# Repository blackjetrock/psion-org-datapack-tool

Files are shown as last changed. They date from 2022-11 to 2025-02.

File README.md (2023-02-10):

# psion-org-datapack-tool
Datapack tool for Psion Organisers

IMAG3168

Status
======

** This is a work in progress and probably always will be **

The code builds and can read datapack data. It can also write datapack data. issues:
the OLED and buttons work and there are read and write and info options that work on the OLED.
A lot of funtionality is over USB serial.

0. There are errors on the fab1 PCB. these are listed in the errata. hand mods are needed to get the PCB to work.
1. Flash packs can't be written.
2. Read pak to file doesn't seem to give a valid opk file, not sure why
3. Detection of all the diffferent pack addressing schemes and sizes isn't there, really.
4. Could do with a detection routine.
5. The code is untidy...
6. The OLED and serial functions aren't very coherent.

Building
========

The firmware directory has the files required for building the code but
they are configured for my file system structure.
They will have to be altered to match the location of your SDK, where the FAT
FS library used will have to be located.

Set the PICO_SDK_DIR environment variable to point to the Pico SDK directory: 

export PICO_SDK_DIR="[where the Pico SDK is]"

create a 'build' directory in the 'firmware' directory and run:
cmake ..

then fix errors (should only be directories, probably the location of the FAT FS library in CMakeLists.txt)

Then :

make

Then program with either a picoprobe or as a UF2 file.

Picoprobe Programming
---------------------

There is a script in the firmware directory 

flash_code.sh

that will use openocd and a picprobe toprogram the code onto a Pico. 
Run this script from the build directory

../flash_code.sh

Openocd needs to be set up as detailed in the Pico documentation.
Some directories may need to be altered to match your structure.

There is also a script

../set_debug_openocd.sh

(also run from the build directory) that will set up gdb for a session. Run this from the 
build directory as well. It is set up to use the TUI (Text User Interface) 
with the -tui command line option, but that can be removed for a standard
gdb CLI experience.

Running
=======

There is an interface on the OLED display that uses the buttons. 

Left button:      Up
Middle Button:    Down
Right Button:     Action/Execute

There is a menu system to access all the functions.

There is also an interface that runs over the USB serial connectin from the 
Pico on the PCB to a host PC. I use minicom on Linux but any terminal emulator should work, 
e.g. the one in the Arduino SDK.

SD Card
=======

The SD card holds .opk images in a directory called 'PAK' that is located in the
root directory of the SD card. The SD card is checked at power on and a message 
appears on the OLED display indicating whether the check was OK or not.

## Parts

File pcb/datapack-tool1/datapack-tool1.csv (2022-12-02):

Id | Designator | Package | Quantity | Designation | Supplier and ref
1 | U4 | SOT-223-3_TabPin2 | 1 | AMS1117-3.3
2 | JP6,JP5,JP4,JP3,JP2,JP1 | SolderJumper-2_P1.3mm_Open_TrianglePad1.0x1.5mm | 6 | Jumper_NO_Small
3 | C2,C1,C17 | C_0805_2012Metric | 3 | 100nF
4 | J1 | PinHeader_1x04_P2.54mm_Vertical | 1 | Conn_01x04_Female
5 | U1 | RPi_Pico_SMD_TH | 1 | Pico
6 | J2 | PinHeader_2x08_P2.54mm_Horizontal_psionSide | 1 | Conn_02x08_Odd_Even
7 | XS1 | Conn_uSDcard | 1 | 502p_SD_ebay-uSD-push_push_SMD
8 | U6 | SOT-23-6 | 1 | Regulator_Switching_MT3608
9 | U3,U2 | SOP-20_7.5x12.8mm_P1.27mm | 2 | 74LS245
10 | TR1 | SOT-23 | 1 | Si2302CDS-n-channel
11 | SW3,SW2,SW1 | SW_Push_1P1T_NO_Vertical_Wuerth_434133025816 | 3 | sw
12 | R28 | R_0805_2012Metric | 1 | ???????????
13 | R18 | R_0805_2012Metric | 1 | ????
14 | R17 | R_0805_2012Metric | 1 | 100k
15 | R10,R9,R8 | R_0805_2012Metric | 3 | R_Small
16 | R7,R6,R5,R4,R3 | R_0805_2012Metric | 5 | 10k
17 | R2,R1 | C_0402_1005Metric | 2 | 4k7
18 | M1 | SOT-23 | 1 | P-CHANNEL-MOSFET
19 | L1 | L_Coilcraft_LPS5030 | 1 | 22uH
20 | JP12 | SolderJumper-2_P1.3mm_Open_Pad0.8x0.8mm | 1 | SolderJumper_2_Open
21 | JP11 | SolderJumper-2_P1.3mm_Open_Pad0.8x0.8mm | 1 | Jumper_NO_Small
22 | J3 | PinHeader_1x03_P2.54mm_Vertical | 1 | Conn_01x03_Female
23 | D4 | D_SOD-123 | 1 | SS36
24 | C16 | C_1210_3225Metric_Pad1.33x2.70mm_HandSolder | 1 | 10uF
25 | C15,C14 | C_1210_3225Metric_Pad1.33x2.70mm_HandSolder | 2 | 22uF

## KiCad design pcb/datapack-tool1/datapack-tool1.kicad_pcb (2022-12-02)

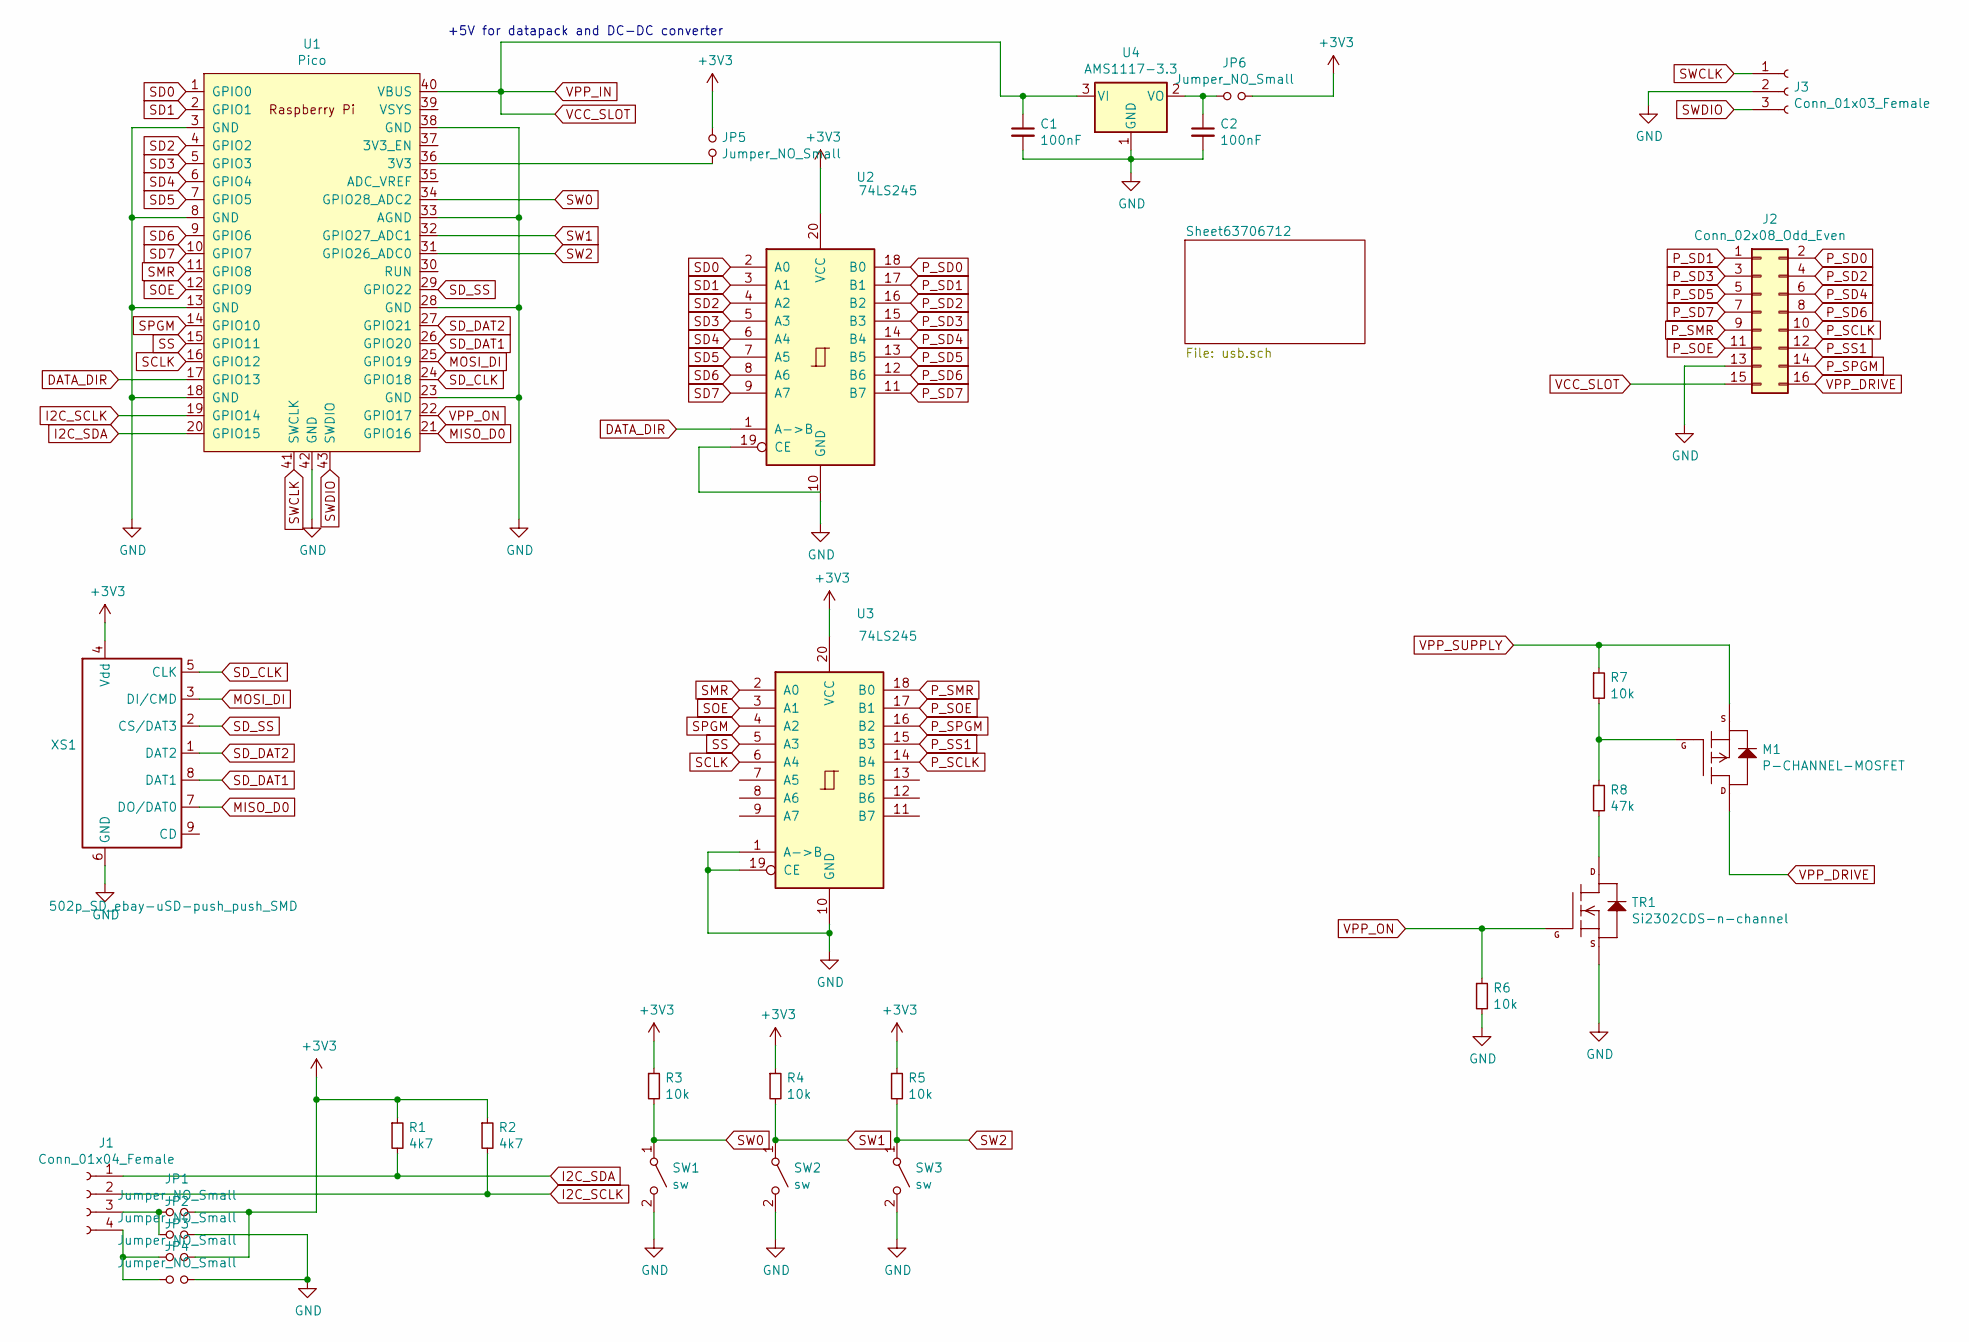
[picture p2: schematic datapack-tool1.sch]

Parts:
C1, C2: 100nF; C_0805_2012Metric
J1: Conn_01x04_Female; PinHeader_1x04_P2.54mm_Vertical
J2: Conn_02x08_Odd_Even; PinHeader_2x08_P2.54mm_Horizontal_psionSide
J3: Conn_01x03_Female; PinHeader_1x03_P2.54mm_Vertical
JP1, JP2, JP3, JP4, JP5, JP6: Jumper_NO_Small; SolderJumper-2_P1.3mm_Open_TrianglePad1.0x1.5mm
M1: P-CHANNEL-MOSFET; SOT-23
R1, R2: 4k7; C_0402_1005Metric
R3, R4, R5, R6, R7: 10k; R_0805_2012Metric
R8: 47k; R_0805_2012Metric
SW1, SW2, SW3: sw; SW_Push_1P1T_NO_Vertical_Wuerth_434133025816
TR1: Si2302CDS-n-channel; SOT-23
U1: Pico; RPi_Pico_SMD_TH
U2, U3: 74LS245; SOP-20_7.5x12.8mm_P1.27mm
U4: AMS1117-3.3; SOT-223-3_TabPin2
XS1: 502p_SD_ebay-uSD-push_push_SMD; Conn_uSDcard

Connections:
+3V3: JP1.2, JP3.2, JP5.1, JP6.2, R1.1, R2.1, R3.1, R4.1, R5.1, U2.20 (VCC), U3.20 (VCC), XS1.4 (Vdd)
DATA_DIR: U1.17 (GPIO13), U2.1 (A->B)
GND: C1.2, C2.2, J2.13, J3.2, JP2.2, JP4.2, R6.2, SW1.2 (B), SW2.2 (B), SW3.2 (B), TR1.2 (S), U1.3 (GND), U1.8 (GND), U1.13 (GND), U1.18 (GND), U1.23 (GND), U1.28 (GND), U1.33 (AGND), U1.38 (GND), U1.42 (GND), U2.10 (GND), U3.1 (A->B), U3.10 (GND), U3.19 (CE), U4.1 (GND), XS1.6 (GND); also elsewhere on the board
I2C_SCLK: J1.2, R2.2, U1.19 (GPIO14)
I2C_SDA: J1.1, R1.2, U1.20 (GPIO15)
MISO_D0: U1.21 (GPIO16), XS1.7 (DO/DAT0)
MOSI_DI: U1.25 (GPIO19), XS1.3 (DI/CMD)
unnamed: C2.1, JP6.1, U4.2 (VO)
unnamed: J1.3, JP1.1, JP2.1
unnamed: J1.4, JP3.1, JP4.1
unnamed: JP5.2, U1.36 (3V3)
unnamed: M1.1 (G), R7.2, R8.1
unnamed: R8.2, TR1.3 (D)
P_SCLK: J2.10, U3.14 (B4)
P_SD0: J2.2, U2.18 (B0)
P_SD1: J2.1, U2.17 (B1)
P_SD2: J2.4, U2.16 (B2)
P_SD3: J2.3, U2.15 (B3)
P_SD4: J2.6, U2.14 (B4)
P_SD5: J2.5, U2.13 (B5)
P_SD6: J2.8, U2.12 (B6)
P_SD7: J2.7, U2.11 (B7)
P_SMR: J2.9, U3.18 (B0)
P_SOE: J2.11, U3.17 (B1)
P_SPGM: J2.14, U3.16 (B2)
P_SS1: J2.12, U3.15 (B3)
SCLK: U1.16 (GPIO12), U3.6 (A4)
SD0: U1.1 (GPIO0), U2.2 (A0)
SD1: U1.2 (GPIO1), U2.3 (A1)
SD2: U1.4 (GPIO2), U2.4 (A2)
SD3: U1.5 (GPIO3), U2.5 (A3)
SD4: U1.6 (GPIO4), U2.6 (A4)
SD5: U1.7 (GPIO5), U2.7 (A5)
SD6: U1.9 (GPIO6), U2.8 (A6)
SD7: U1.10 (GPIO7), U2.9 (A7)
SD_CLK: U1.24 (GPIO18), XS1.5 (CLK)
SD_DAT1: U1.26 (GPIO20), XS1.8 (DAT1)
SD_DAT2: U1.27 (GPIO21), XS1.1 (DAT2)
SD_SS: U1.29 (GPIO22), XS1.2 (CS/DAT3)
SMR: U1.11 (GPIO8), U3.2 (A0)
SOE: U1.12 (GPIO9), U3.3 (A1)
SPGM: U1.14 (GPIO10), U3.4 (A2)
SS: U1.15 (GPIO11), U3.5 (A3)
SW0: R3.2, SW1.1 (A), U1.34 (GPIO28_ADC2)
SW1: R4.2, SW2.1 (A), U1.32 (GPIO27_ADC1)
SW2: R5.2, SW3.1 (A), U1.31 (GPIO26_ADC0)
SWCLK: J3.1, U1.41 (SWCLK)
SWDIO: J3.3, U1.43 (SWDIO)
VCC_SLOT: C1.1, J2.15, U1.40 (VBUS), U4.3 (VI); also elsewhere on the board
VPP_DRIVE: J2.16, M1.3 (D)
VPP_ON: R6.1, TR1.1 (G), U1.22 (GPIO17)
VPP_SUPPLY: M1.2 (S), R7.1; also elsewhere on the board

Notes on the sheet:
+5V for datapack and DC-DC converter

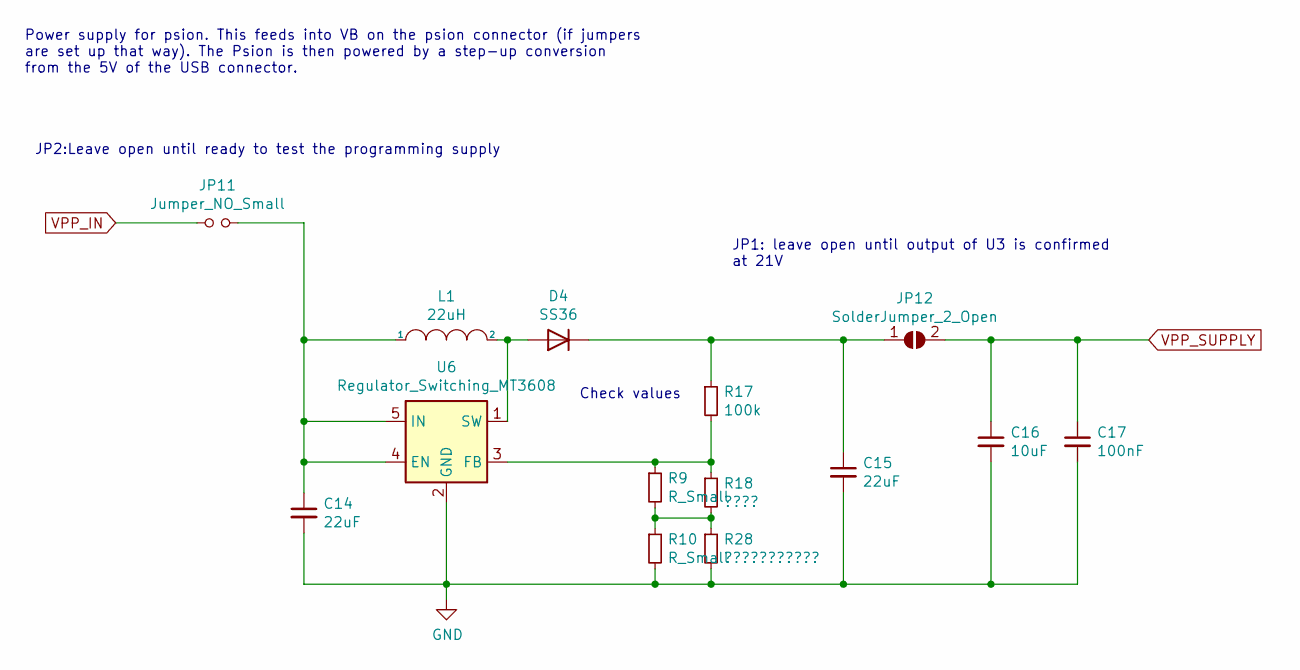
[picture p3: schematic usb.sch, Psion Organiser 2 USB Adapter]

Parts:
C14, C15: 22uF; C_1210_3225Metric_Pad1.33x2.70mm_HandSolder
C16: 10uF; C_1210_3225Metric_Pad1.33x2.70mm_HandSolder
C17: 100nF; C_0805_2012Metric
D4: SS36; D_SOD-123
JP11: Jumper_NO_Small; SolderJumper-2_P1.3mm_Open_Pad0.8x0.8mm
JP12: SolderJumper_2_Open; SolderJumper-2_P1.3mm_Open_Pad0.8x0.8mm
L1: 22uH; L_Coilcraft_LPS5030
R9, R10: R_Small; R_0805_2012Metric
R17: 100k; R_0805_2012Metric
R18: ????; R_0805_2012Metric
R28: ???????????; R_0805_2012Metric
U6: Regulator_Switching_MT3608; SOT-23-6

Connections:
GND: C14.2, C15.2, C16.2, C17.2, R10.2, R28.2, U6.2 (GND); also elsewhere on the board
unnamed: C14.1, JP11.2, L1.1, U6.4 (EN), U6.5 (IN)
unnamed: C15.1, D4.1 (K), JP12.1 (A), R17.1
unnamed: D4.2 (A), L1.2, U6.1 (SW)
unnamed: R9.2, R10.1, R18.2, R28.1
unnamed: R9.1, R17.2, R18.1, U6.3 (FB)
VCC_SLOT: JP11.1; also elsewhere on the board
VPP_SUPPLY: C16.1, C17.1, JP12.2 (B); also elsewhere on the board

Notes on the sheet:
Check values
JP1: leave open until output of U3 is confirmed at 21V
JP2:Leave open until ready to test the programming supply
Power supply for psion. This feeds into VB on the psion connector (if jumpers are set up that way). The Psion is then powered by a step-up conversion from the 5V of the USB connector.

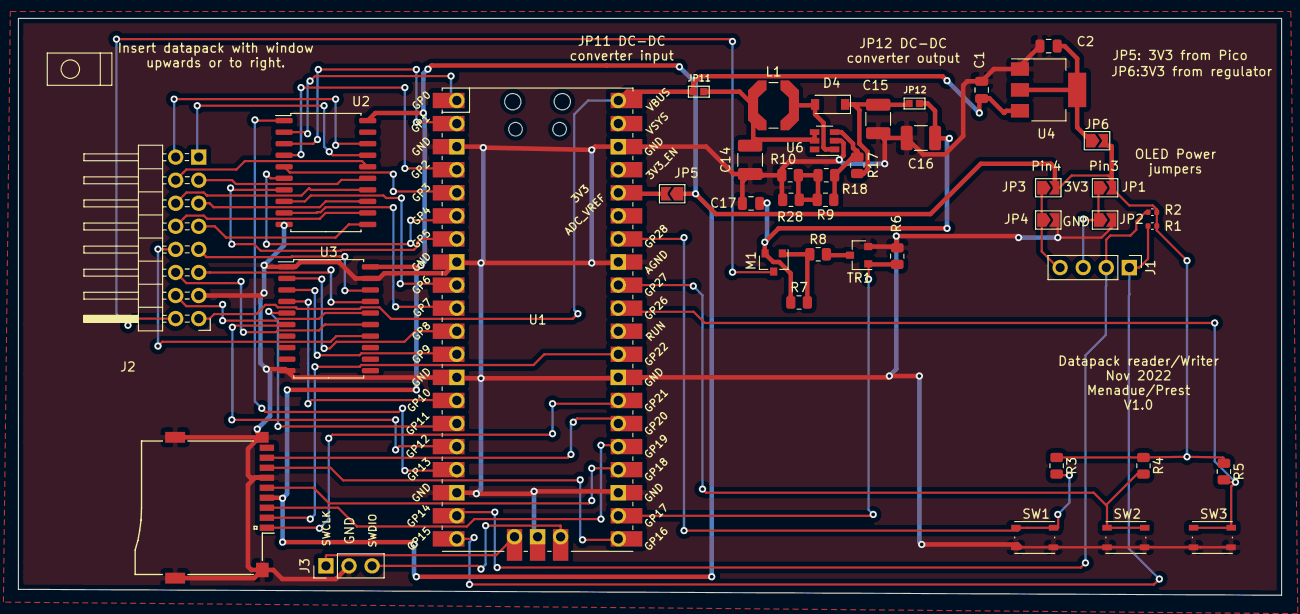
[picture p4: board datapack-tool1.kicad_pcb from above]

Board: 2 copper layers, 139.1 x 63.5 mm, 43 parts (0 on the bottom side), 57 nets.

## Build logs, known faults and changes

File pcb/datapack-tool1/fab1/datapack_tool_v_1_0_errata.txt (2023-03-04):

Psion Organiser datapack Tool V1.0 errata
=========================================

1. Datapack connector is awkward
2. 4k7 pull ups for I2C have wrong footprint
3. Potentiometer needed in vpp supply
4. 3608 dc-dc converter doesn't work and destroys the IC even
   though a 3608 dc-dc module does work.
5. Pin 19 of U2 should go to GND (schematic issue)
6. Data direction of U3 is wrong. Should be high as we want Pico to
   drive the signals to the slot.
7. Make inductor footprint bigger/more universal to allow
   selection of more inductors
8. Add circuit to make VCC switchable.

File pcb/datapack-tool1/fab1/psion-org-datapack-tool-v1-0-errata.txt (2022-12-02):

Psion Organiser Datapack Tool V1.0 Errata
=========================================

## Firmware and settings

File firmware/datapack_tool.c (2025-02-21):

////////////////////////////////////////////////////////////////////////////////
//
// Psion Organiser Datapack Tool Control Program
//
// This is an early version of the code which is a copy
// of the pak_gadget code with enough changes to test the
// first version of the hardware wrt the display, keys and
// SD card.
//
// It does not have working datapack functionality, that has to ported from
// other datapack tool code
//
////////////////////////////////////////////////////////////////////////////////

#include <stdarg.h>
#include <ctype.h>
#include <stdio.h>
#include <string.h>
#include <stdlib.h>
#include "pico/stdlib.h"
#include "hardware/pio.h"
#include "hardware/clocks.h"
#include "pico/multicore.h"
#include "pico/bootrom.h"

#include "f_util.h"

#include "ff.h"
#include "ff_stdio.h"
#include "hw_config.h"
#include "my_debug.h"
#include "rtc.h"
#include "sd_card.h"

typedef uint8_t byte;
typedef uint16_t word;
typedef int boolean;


boolean paged_addr                  = true;     // true for paged addressing, false for linear addressing - note linear addressing is untested!! - paged is default
boolean datapak_mode                = true;     // true for datapaks, false for rampaks, mode can be changed by command option
boolean program_low                 = false;    // will be set true when SLOT_SPGM_PIN is low during datapak write, so page counter can be pulsed accordingly
const boolean force_write_cycles    = false;    // set true to perform max write cycles, without break for confirmed write
const boolean overwrite             = false;    // set true to add a longer overwite after confirmed write
const byte max_datapak_write_cycles = 50 ;        // max. no. of write cycle attempts before failure
const int datapak_write_pulse      = 1000;      // datapak write pulse in us, 1000 us = 1 ms, 10us write can be read by Arduino, but not Psion!
word current_address                = 0;
#define max_eprom_size              0x8000      // max eprom size - 32k - only used by Matt's code

boolean read_fixed_size             = false;    // true for fixed size
//boolean read_fixed_size           = true;     // true for fixed size
word read_pack_size                 = 0x7e9b;   // set a fixed pack size for read
//word read_pack_size               = 0x0100; 

byte CLK_val                        = 0;        // flag to indicate CLK state

// Use this if breakpoints don't work
#define DEBUG_STOP {volatile int x = 1; while(x) {} }

// Are we compiling for the gadget breakout or the picopak?
#define PICOPAK 0

// Drop into a loop that displays key states and does nothing else
#define KEY_DEBUG_ONLY                0

// Adjustable delay in nextAddress for debug
#define TUNED_CLK_DELAY  1

// Do multiple reads of data and check for stability
#define CHECK_STABLE     1
#define INDICATE_UNSTABLE  1

int page_byte_unstable[256];

// Interrupts may muck up the pack interface, but it does seem to run with them enabled.
// If USB is ever to work then interrupts need to be enabled.
#define NO_INTERRUPTS_WHILE_POLLING   0
#define TEST_STDIO                    0

// Checksums of page data
int last_checksum = 0;

// Redefine pins to match our hardware
// datapack tool port note:
//
// We have SD clock defined as pin 5 here, but that is wired to SW3 so
// this doesn't make sense. It does seem to work, though.
// The actual clock pin is on GPIO18, which is CMD here, so I don't know what's
// going on

#define PICO_SD_CLK_PIN        5
#define PICO_SD_CMD_PIN       18
#define PICO_SD_DAT0_PIN      19
#define ENABLE_4_PIN           0

#define SUPPORT_ID_BYTE        1
#define PAK_ID_BYTE         0x01
#define READ_ONLY              0
#define INIT_PAK_MEMORY        0
#define FF_FIRST_BYTES         0

// Direct access to GPIO registers is faster, and we need speed
#define DIRECT_GPIO            1

// Number of buttons used for the menu system. The 'exit polling' button is not in this
// list, it is coded as a GPIO line as we don't want to waste time processing the menu
// buttons in the fast polling loop

#define NUM_BUTTONS            3

// All organiser files are in this subdirectory on the SD card, just to keep things tidy
// and allow the card to be used for other things if needed.
#define PAK_DIR                "/PAK"

// Debounce
#define MAX_BUT_COUNT          6

bool sd_ok_flag = false;

// Do we use a polling loop of interrupts?
#define USE_INTERRUPTS         0
#define USE_POLLING            1

// For added speed, we poll the address counter stuff on the other core
#define MULTICORE_POLL         1

// The address into pak memory
#define PAK_ADDRESS (ss_address | ss_page)
//#define PAK_ADDRESSxxx (ss_address)

// Pack ID byte
#define PACK_ID_PAGED  0x04

// For the OLED display
const uint SDA_PIN             = 15;
const uint SCL_PIN             = 14;

#ifndef I2C_FUNCTIONS_H_
#define I2C_FUNCTIONS_H_

typedef unsigned char BYTE;

// Buttons got changed for PCB layout reasons
#if 0
const int SW0_PIN       = 0;
const int SW1_PIN       = 1;
const int SW2_PIN       = 5;
const int SW3_PIN       = 26;
#else
const int SW0_PIN       = 28;
const int SW1_PIN       = 27;
const int SW2_PIN       = 26;
//const int SW3_PIN       = 5;
#endif

const int SLOT_SPGM_PIN = 10;
const int SLOT_SS_PIN   = 11;
const int SLOT_SCLK_PIN = 12;

const int SLOT_SOE_PIN  = 9;
const int SLOT_SMR_PIN  = 8;

const int SLOT_SD0_PIN  = 0;
const int SLOT_SD1_PIN  = 1;
const int SLOT_SD2_PIN  = 2;
const int SLOT_SD3_PIN  = 3;
const int SLOT_SD4_PIN  = 4;
const int SLOT_SD5_PIN  = 5;
const int SLOT_SD6_PIN  = 6;
const int SLOT_SD7_PIN  = 7;

const byte data_pin[8] =
  {
   SLOT_SD0_PIN,
   SLOT_SD1_PIN,
   SLOT_SD2_PIN,
   SLOT_SD3_PIN,
   SLOT_SD4_PIN,
   SLOT_SD5_PIN,
   SLOT_SD6_PIN,
   SLOT_SD7_PIN
  }; // pins D0 to D7 on Datapak

const int data_gpio[8] =
  {
   SLOT_SD0_PIN,
   SLOT_SD1_PIN,
   SLOT_SD2_PIN,
   SLOT_SD3_PIN,
   SLOT_SD4_PIN,
   SLOT_SD5_PIN,
   SLOT_SD6_PIN,
   SLOT_SD7_PIN,
  };

const int LS_DIR_PIN    = 13;
const int VPP_ON_PIN    = 17;

volatile int ss_count = 0;
volatile int soe_state = 1;
volatile int ss_address = 0;
volatile int ss_page = 0;

// Manual mode states

int man_smr_state  = 0;
int man_sclk_state = 0;
int man_spgm_state = 0;
int man_soe_state  = 0;
int man_ss_state   = 0;

// Memory that emulates a pak
typedef unsigned char BYTE;
typedef void (*FPTR)(void);
typedef void (*CMD_FPTR)(char *cmd);


// Serial loop command structure
typedef struct
{
  char key;
  char *desc;
  FPTR fn;
} SERIAL_COMMAND;

// The tracing was used for low level analysis of the protocol
#define TRACE_LENGTH 2
BYTE trace0[TRACE_LENGTH];
BYTE trace1[TRACE_LENGTH];

void nextPage();

volatile int trace_i = 0;
#define TRACE0(XX) if(trace_i != (TRACE_LENGTH-1)) {trace0[trace_i++] = XX; /*trace_i %= TRACE_LENGTH;*/}
#define TRACE1(XX) if(trace_i != (TRACE_LENGTH-1)) {trace1[trace_i++] = XX; /*trace_i %= TRACE_LENGTH;*/}

//#define TRACE(XX)

//#define WRITE_TRAP if( (PAK_ADDRESS + data) == 0)  while(1);

#define WRITE_TRAP

//#define PAK_MEMORY_SIZE  65536
#define PAK_MEMORY_SIZE  (128*1024)
//#define PAK_MEMORY_SIZE  32768

// Allow a file to be selected. The file name will be stored for a later 'read' command.

int file_offset = 0;
int max_filenum = 0;

// File names for paks that are written to SD card
#define FILE_PAGE 7
#define PAK_FILE_NAME_FORMAT "pak%05d.opk"
#define PAK_FILE_NAME_GLOB   "pak*.opk"

// I2C Port descriptor
typedef struct _I2C_PORT_DESC
{
  unsigned char sdaport;
  unsigned char sdabit;
  unsigned char sclport;
  unsigned char sclbit;
} I2C_PORT_DESC;


// Slave device descriptor
typedef struct _I2C_SLAVE_DESC
{
  I2C_PORT_DESC *port;             // Port the device is on
  unsigned char slave_7bit_addr;        // SLave address
} I2C_SLAVE_DESC;


#if PICOPAK
#define MENU_MAX  3
#else
#define MENU_MAX  6
#endif

int menu_offset = 0;

typedef struct _BUTTON
{
  int     count;
  bool pressed;
  bool last_pressed;   // For edge detection
  FPTR    event_fn;
} BUTTON;

BUTTON buttons[NUM_BUTTONS];
enum ELEMENT_TYPE
  {
   BUTTON_ELEMENT = 10,
   SUB_MENU,
   MENU_END,
  };

struct MENU_ELEMENT
{
  enum ELEMENT_TYPE type;
  char *text;
  const void *submenu;
  void (*function)(struct MENU_ELEMENT *e);
};

void button_display(struct MENU_ELEMENT *e);
void button_list(struct MENU_ELEMENT *e);
void button_pak_id(struct MENU_ELEMENT *e);
void button_pak_hdr(struct MENU_ELEMENT *e);
void button_blank(struct MENU_ELEMENT *e);

//void but_ev_file_up();
//void but_ev_file_down();
void but_ev_file_select();

#define REAL_US_DELAYS 1
#define DELAY_FACTOR  100

#if REAL_US_DELAYS

void loop_delay(int delay)
{
  sleep_us(delay);
}

#else

void loop_delay(int delay)
{
  volatile x, y;

  for(x=0; x<delay; x++)
    {
      for(y=0; y<10; y++)
	{
	}
    }
}

#endif

int menuloop_done = 0;

////////////////////////////////////////////////////////////////////////////////
//
// Prototypes
//
////////////////////////////////////////////////////////////////////////////////

word read_dir(void);
void write_opk_file(I2C_SLAVE_DESC *slave, char *filename);
void read_opk_file(I2C_SLAVE_DESC *slave, char *filename);
void button_compare_file(struct MENU_ELEMENT *e);
void compare_opk_file(I2C_SLAVE_DESC *slave, char *filename);
byte readByte();
int cd_to_pak_dir(I2C_SLAVE_DESC *slave);
void auto_size(int oled_nserial);
void ArdDataPinsToOutput();
void packOutputAndSelect();
void packDeselectAndInput();
byte readByte();
void ArdDataPinsToInput(void);
void nextAddress();
void resetAddrCounter();

////////////////////////////////////////////////////////////////////////////////

#if !INIT_PAK_MEMORY
BYTE pak_memory[PAK_MEMORY_SIZE];
#else

// Complete 'angling' pack embedded in flash. It is probably possible to store
// every known pack in SPI flash and not use the SD card at all. Obviously with no
// SD card there's no saving of packs, though.

BYTE pak_memory[PAK_MEMORY_SIZE] =
  {
   0x78,0x04,0x56,0x00,0x03,0x02,0x35,0x46,0x06,0x4c,
   0x09,0x81,0x4d,0x41,0x49,0x4e,0x20,0x20,0x20,0x20,0x90,0x09,0x83,0x46,0x49,0x53,
   0x48,0x20,0x20,0x20,0x20,0x00,0x02,0x80,0x01,0x26,0x01,0x22,0x00,0x29,0x00,0xfc,
   0x00,0x00,0x13,0x02,0x59,0x25,0x00,0xff,0xe9,0x03,0x44,0x52,0x24,0x02,0xff,0xe6,
   0x02,0x46,0x24,0x02,0xff,0xdc,0x00,0x00,0x00,0x06,0xff,0xe5,0x02,0xff,0xdb,0x08,
   0x00,0x00,0x0f,0xff,0xdc,0x24,0x04,0x46,0x49,0x53,0x48,0x20,0x02,0x20,0x01,0x7d,
   0x06,0x45,0x58,0x49,0x53,0x54,0x24,0x81,0x02,0xff,0xdc,0x24,0x00,0x4a,0x7e,0x00,
   0x32,0x0d,0xff,0xd9,0x24,0x10,0x43,0x52,0x45,0x41,0x54,0x45,0x2d,0x46,0x49,0x4c,
   0x45,0x2c,0x51,0x55,0x49,0x54,0x98,0x7f,0x00,0xff,0xd9,0x022,0x00,0x01,0x2c,0x7e,
   0x00,0x10,0x20,0x00,0x7d,0x06,0x46,0x49,0x53,0x48,0x43,0x52,0x84,0x51,0x00,0x03,
   0x7b,0x20,0x00,0x7d,0x06,0x46,0x49,0x53,0x48,0x4f,0x50,0x84,0x20,0x00,0x7d,0x06,
   0x4d,0x41,0x44,0x55,0x44,0x47,0x84,0x0d,0xff,0xd7,0x24,0x20,0x41,0x44,0x44,0x2d,
   0x4e,0x45,0x57,0x2d,0x46,0x49,0x53,0x48,0x2c,0x53,0x45,0x41,0x52,0x43,0x48,0x2c,
   0x52,0x45,0x50,0x4f,0x52,0x54,0x2c,0x55,0x54,0x49,0x4c,0x53,0x98,0x7f,0x00,0xff,
   0xd7,0x22,0x00,0x01,0x2c,0x7e,0x00,0x14,0x20,0x00,0x7d,0x07,0x46,0x49,0x53,0x48,
   0x41,0x44,0x44,0x84,0x51,0xff,0xc2,0x51,0x00,0x55,0x00,0xff,0xd7,0x22,0x00,0x02,
   0x2c,0x7e,0x00,0x14,0x20,0x00,0x7d,0x07,0x46,0x49,0x53,0x48,0x53,0x45,0x45,0x84,
   0x51,0xff,0xa6,0x51,0x00,0x39,0x00,0xff,0xd7,0x22,0x00,0x03,0x2c,0x7e,0x00,0x14,
   0x20,0x00,0x7d,0x07,0x46,0x49,0x53,0x48,0x52,0x45,0x50,0x84,0x51,0xff,0x8a,0x51,
   0x00,0x1d,0x00,0xff,0xd7,0x22,0x00,0x04,0x2c,0x7e,0x00,0x12,0x20,0x00,0x7d,0x05,
   0x55,0x54,0x49,0x4c,0x53,0x84,0x51,0xff,0x70,0x51,0x00,0x03,0x7b,0x7b,0x00,0x00,
   0x09,0x83,0x46,0x49,0x53,0x48,0x41,0x44,0x44,0x20,0x00,0x02,0x80,0x06,0x11,0x06,
   0x0d,0x00,0x3a,0x05,0xee,0x00,0x00,0x00,0x00,0x00,0x00,0x12,0xff,0xf4,0x06,0xff,
   0xe6,0x04,0xff,0xe2,0x02,0xff,0xde,0x02,0xff,0xd8,0x04,0xff,0xc6,0x10,0x00,0x00,
   0x4e,0x24,0x0f,0x45,0x58,0x45,0x20,0x74,0x6f,0x20,0x63,0x6f,0x6e,0x74,0x69,0x6e,
   0x75,0x65,0x71,0x73,0x24,0x0d,0x43,0x4c,0x45,0x41,0x52,0x20,0x74,0x6f,0x20,0x71,
   0x75,0x69,0x74,0x71,0x73,0x0d,0xff,0xfc,0x91,0x7f,0x00,0xff,0xfc,0x22,0x00,0x0d,
   0x2b,0x7e,0x00,0x03,0x7b,0x4e,0x62,0x24,0x04,0x44,0x41,0x59,0x24,0x1f,0x00,0xb9,
   0x22,0x00,0x10,0xc0,0x81,0x0f,0xff,0xc7,0x24,0x04,0x44,0x41,0x59,0x24,0x1c,0x00,
   0x81,0x24,0x04,0x44,0x41,0x59,0x24,0x1f,0x00,0x6b,0x24,0x04,0x44,0x41,0x59,0x24,
   0x1c,0x00,0x02,0xff,0xc7,0x49,0x7e,0x00,0x85,0x53,0xff,0xff,0x24,0x04,0x44,0x41,
   0x59,0x24,0x1f,0x00,0x24,0x04,0x44,0x41,0x59,0x24,0x1c,0x00,0x22,0x00,0x10,0xc0,
   0x81,0x22,0x00,0x03,0x6a,0x0f,0xff,0xe3,0x8c,0x86,0x22,0x00,0x02,0xbc,0x81,0x0f,
   0xff,0xdf,0x9a,0x86,0x22,0x00,0x02,0xbc,0x81,0x0f,0xff,0xd9,0xa1,0x86,0x22,0x00,
   0x04,0xbc,0x81,0x22,0x00,0x01,0x22,0x00,0x02,0x4c,0x0f,0xff,0xe3,0x6b,0x22,0x00,
   0x04,0x22,0x00,0x02,0x4c,0x0f,0xff,0xdf,0x6b,0x22,0x00,0x08,0x22,0x00,0x02,0x4c,
   0x0f,0xff,0xd9,0x6b,0x24,0x01,0x44,0x1e,0x00,0x02,0xff,0xe3,0xb5,0x02,0xff,0xdf,
   0xb5,0x22,0x00,0x64,0x86,0x3e,0x3c,0x02,0xff,0xd9,0xb5,0x22,0x27,0x10,0x86,0x3e,
   0x3c,0x80,0x22,0x00,0x01,0x6a,0x53,0x00,0x00,0x51,0x00,0x24,0x24,0x01,0x44,0x1e,
   0x00,0xa1,0x86,0x80,0x24,0x01,0x44,0x1e,0x00,0x24,0x01,0x44,0x1b,0x00,0x22,0x27,
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
  };
#endif

////////////////////////////////////////////////////////////////////////////////
//
typedef struct {
  FATFS fatfs;
  char const *const name;
} fatfs_dscr_t;

fatfs_dscr_t fatfs_dscrs[2] = {{.name = "0:"}, {.name = "1:"}};
FATFS *get_fs_by_name(const char *name) {
  for (size_t i = 0; i < count_of(fatfs_dscrs); ++i) {
    if (0 == strcmp(fatfs_dscrs[i].name, name)) {
      return &fatfs_dscrs[i].fatfs;
    }
  }
  return NULL;

}

bool logger_enabled;
const uint32_t period = 1000;
absolute_time_t next_time;

void button_select_file(struct MENU_ELEMENT *e);

////////////////////////////////////////////////////////////////////////////////



// I2C functions
void i2c_release(I2C_PORT_DESC *port);
void i2c_delay(I2C_PORT_DESC *port);
void i2c_sda_low(I2C_PORT_DESC *port);
void i2c_sda_high(I2C_PORT_DESC *port);
void i2c_scl_low(I2C_PORT_DESC *port);
void i2c_scl_high(I2C_PORT_DESC *port);
void i2c_start(I2C_PORT_DESC *port);
void i2c_stop(I2C_PORT_DESC *port);
int i2c_send_byte(I2C_PORT_DESC *port, BYTE b);
int i2c_read_bytes(I2C_SLAVE_DESC *slave, int n, BYTE *data);
void i2c_send_bytes(I2C_SLAVE_DESC *slave, int n, BYTE *data);
#


#endif /* I2C_FUNCTIONS_H_ */


/*
 * i2c_functions.c
 *
 *  Created on: 23 Jul 2016
 *      Author: menadue
 */
//#include "chip.h"
//#include "board.h"
//#include "i2c_functions.h"


// I2C functions

// Release the bus
void i2c_release(I2C_PORT_DESC *port) {
  // All inputs
  gpio_set_dir(SDA_PIN,GPIO_OUT);
  gpio_set_dir(SCL_PIN,GPIO_OUT);
  gpio_put(SDA_PIN, 0);
  gpio_put(SCL_PIN, 0);
  
  //  Chip_GPIO_SetPinDIRInput(LPC_GPIO, port->sdaport, port->sdabit);
  //Chip_GPIO_SetPinDIRInput(LPC_GPIO, port->sclport, port->sclbit);
}

// Delay to slow down to I2C bus rates
void i2c_delay(I2C_PORT_DESC *port) {
  sleep_us(1);
  return;
  volatile int i;
  for(i=0; i<1; i++)
    {
    }
  
}

void i2c_sda_low(I2C_PORT_DESC *port)
{
  // Take SCL low by driving a 0 on to the bus
  gpio_set_dir(SDA_PIN,GPIO_OUT);
  gpio_put(SDA_PIN, 0);
  //Chip_GPIO_SetPinState(LPC_GPIO, port->sdaport, port->sdabit, 0);
  
  // Make sure bit is an output
  //Chip_GPIO_SetPinDIROutput(LPC_GPIO, port->sdaport, port->sdabit);
}

void i2c_sda_high(I2C_PORT_DESC *port)
{
  // Make sure bit is an input
  gpio_set_dir(SDA_PIN,GPIO_IN);
  //  gpio_put(SDA_PIN, 1);
  //  Chip_GPIO_SetPinDIRInput(LPC_GPIO, port->sdaport, port->sdabit);
}

void i2c_scl_low(I2C_PORT_DESC *port) {

  gpio_set_dir(SCL_PIN,GPIO_OUT);
  gpio_put(SCL_PIN, 0);
  
  //  Chip_GPIO_SetPinState(LPC_GPIO, port->sclport, port->sclbit, 0);

  // Make sure bit is an output
  //Chip_GPIO_SetPinDIROutput(LPC_GPIO, port->sclport, port->sclbit);
}

void i2c_scl_high(I2C_PORT_DESC *port)
{
  // Make sure bit is an input
  gpio_set_dir(SCL_PIN, GPIO_IN);
  //gpio_put(SCL_PIN, 1);
  //Chip_GPIO_SetPinDIRInput(LPC_GPIO, port->sclport, port->sclbit);
}

// Read ACK bit

int i2c_read_sda(I2C_PORT_DESC *port)
{
  return(gpio_get(SDA_PIN));
  //  return(Chip_GPIO_GetPinState(LPC_GPIO, port->sdaport, port->sdabit));

  //  return( ((*(port->port)) & (port->sda_mask)) == port->sda_mask);
}

// I2C start condition

void i2c_start(I2C_PORT_DESC *port)
{
  //
  i2c_sda_low(port);

  i2c_delay(port);
  i2c_scl_low(port);
  i2c_delay(port);
}

void i2c_stop(I2C_PORT_DESC *port)
{
  i2c_scl_high(port);
  i2c_delay(port);
  i2c_sda_high(port);
  i2c_delay(port);

}

// Send 8 bits and read ACK
// Returns number of acks received

int i2c_send_byte(I2C_PORT_DESC *port, BYTE b)
{
  int i;
  int ack=0;
  int retries = 100;
  int rc =1;

  for (i = 0; i < 8; i++)
    {
      // Set up data
      if ((b & 0x80) == 0x80)
	{
	  i2c_sda_high(port);
	} else
	{
	  i2c_sda_low(port);
	}

      // Delay
      i2c_delay(port);

      // Take clock high and then low
      i2c_scl_high(port);

      // Delay
      i2c_delay(port);

      // clock low again
      i2c_scl_low(port);

      // Delay
      i2c_delay(port);

      // Shift next data bit in
      b <<= 1;
    }

  // release data line
  i2c_sda_high(port);

  // Now get ACK
  i2c_scl_high(port);

  i2c_delay(port);

  // read ACK

  while( ack = i2c_read_sda(port) ) // @suppress("Assignment in condition")
    {
      retries--;

      if ( retries == 0 )
	{
	  rc = 0;
	  break;
	}
    }

  i2c_scl_low(port);

  i2c_delay(port);
  return (rc);
}
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
int main()
{
  char line[80];

  // Turn VPP off immediately
  gpio_init(VPP_ON_PIN);
  gpio_put(VPP_ON_PIN, 0);
  gpio_set_dir(VPP_ON_PIN, GPIO_OUT);

  // Set up default file name, default is angling pak
  strcpy(current_file, "angler.opk");
  
#if FF_FIRST_BYTES
  for(int k=0; k< 100; k++)
    {
      pak_memory[k] = 0xff;
    }
#endif

  stdio_init_all();
  loop_delay(2000000);

  printf("\n\nPsion Organiser Datapack Tool V2.1 Feb 2025\n\n");
  printf("\nInitialising...");
  printf("\nSetting GPIOs...");
  
  // Select the SD card
  gpio_init(22);
  gpio_put(22, 0);
  gpio_set_dir(22, GPIO_OUT);
  gpio_put(22, 0);
  
  // Set up directions for the control lines
  gpio_init(SLOT_SS_PIN);
  gpio_init(SLOT_SCLK_PIN);
  gpio_init(SLOT_SMR_PIN);
  gpio_init(SLOT_SOE_PIN);
  gpio_init(SLOT_SPGM_PIN);

  for(int i=0; i<8; i++)
    {
      gpio_init(data_gpio[i]);
      gpio_set_dir(data_gpio[i], GPIO_IN);
    }
  
  gpio_set_dir(SLOT_SS_PIN, GPIO_OUT);
  gpio_set_dir(SLOT_SCLK_PIN, GPIO_OUT);
  gpio_set_dir(SLOT_SMR_PIN, GPIO_OUT);
  gpio_set_dir(SLOT_SOE_PIN, GPIO_OUT);
  gpio_set_dir(SLOT_SPGM_PIN, GPIO_OUT);

  // Deselect the datapack
  gpio_put(SLOT_SS_PIN, 1);
  
  // Drive data bus towards us
  gpio_init(LS_DIR_PIN);
  gpio_put(LS_DIR_PIN, 0);

  // LS_DIR is an output
  gpio_set_dir(LS_DIR_PIN, GPIO_OUT);

#if 0
  gpio_set_irq_enabled_with_callback(SLOT_SS_PIN,   GPIO_IRQ_EDGE_RISE | GPIO_IRQ_EDGE_FALL, true, &gpio_callback);
  gpio_set_irq_enabled_with_callback(SLOT_SCLK_PIN, GPIO_IRQ_EDGE_RISE | GPIO_IRQ_EDGE_FALL, true, &gpio_callback);
  gpio_set_irq_enabled_with_callback(SLOT_SMR_PIN,  GPIO_IRQ_EDGE_RISE | GPIO_IRQ_EDGE_FALL, true, &gpio_callback);
  gpio_set_irq_enabled_with_callback(SLOT_SOE_PIN,  GPIO_IRQ_EDGE_RISE | GPIO_IRQ_EDGE_FALL, true, &gpio_callback);
  gpio_set_irq_enabled_with_callback(SLOT_SPGM_PIN, GPIO_IRQ_EDGE_RISE | GPIO_IRQ_EDGE_FALL, true, &gpio_callback);
#endif

  printf("\nInitialising SD card driver...");

#define SD_CARD 1
  
#if SD_CARD  
  // Initialise SD card driver
  sd_init_driver();
#endif

#if 1
  printf("\nSetting up buttons...");
  
  // Set up button gpios
  for(int i=0; i<NUM_BUTTONS; i++)
    {
      gpio_init(but_pins[i]);
      gpio_set_dir(but_pins[i], GPIO_IN);

#if PICOPAK      
      // Set pull ups for buttons
      gpio_set_pulls(but_pins[i], 1, 0);
#endif
    }
#endif
  
  printf("\nSetting up OLED...");

#define OLED_ON 1
  
#if OLED_ON  
  // Set up OLED display
  i2c_init(&i2c_bus_0);
    
  oled_setup(&oled0);

  // Set up the OLED menu
  
  current_menu = (struct MENU_ELEMENT *)&(home_menu[0]);
  last_menu = (struct MENU_ELEMENT *)&(home_menu[0]);
  the_home_menu = last_menu;

  to_home_menu(NULL);

  init_buttons();
#endif
  
  int count = 0;

#if SD_CARD  
  // Read config file into memory buffer
  // That will tell us which file to load
  process_config_file(&oled0);
#endif
  
  // datapack tool main loop

  while(1)
    {

      stdio_flush();
#if OLED_ON
      // Overall loop, which contains the polling loop and the menu loop
      oled_clear_display(&oled0);
      
      oled_set_xy(&oled0, 0,0);
      oled_display_string(&oled0, "Datapak Gadget");
      
#if USE_INTERRUPTS
      oled_set_xy(&oled0, 0,14);
      oled_display_string(&oled0, "Interrupts");
#endif
      
      sprintf(line, "%s", current_file);
      oled_set_xy(&oled0, 0, 14);
      oled_display_string(&oled0, line);
#endif
      
#if SD_CARD      
      // Mount and unmount the SD card to set the sd_ok_flag up
      mount_sd();
      unmount_sd();
      
      oled_set_xy(&oled0, 0,21);
      if( sd_ok_flag )
	{
	  oled_display_string(&oled0, "SD card OK");
	  printf("\nSD card OK");
	}
      else
	{
	  oled_display_string(&oled0, "SD card NOT OK");
	  printf("\nSD card NOT OK");
	}

      loop_delay(1000000);
#endif
      
#if 1
      // Indicate we are now in menu
      oled_clear_display(&oled0);
      oled_set_xy(&oled0, 0,0);
      oled_display_string(&oled0, "Datapak Gadget Menu");
#endif

#if OLED_ON
      draw_menu(&oled0, current_menu, true);
#endif
      
      // Menu loop
      menuloop_done = 0;
      //stdio_flush();

      printf("\nReady.\n");
      
      while(!menuloop_done)
	{
	  //	  printf("\nLoop0");
	  stdio_flush();
	  
#if OLED_ON
	  // Run menu
	  update_buttons();
#endif
	  
	  // Run serial interface
	  serial_loop();
	  //printf("\nLoop1\n");
	}
    }
}
  

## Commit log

2022-12-24 Datapack can be read, code hacked about to find problem
    [datapack_tool.c]
2022-12-24 Tidy up. Managed to write a test record to a data pack using 18V as VPP
2023-01-26 Fixed reading a pack image
    [datapack_tool.c]
2023-02-01 Changed delays to proper us, conditionally. Tidied warnings and fixed problem with USB serial locking up for some reason
    [datapack_tool.c]
